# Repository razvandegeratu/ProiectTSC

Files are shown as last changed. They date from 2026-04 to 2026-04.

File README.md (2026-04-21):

Diagramă fără titlu drawio(1)

 Descrierea Funcționalității Hardware
Module și Interfețe

    Microcontroller: nRF52840 gestionează procesarea centrală.

    Display E-Paper: Comunică prin interfața SPI. S-a ales acest tip de ecran datorită consumului de energie zero în stare statică.

    Senzor IMU: Conectat prin I2C, utilizat pentru detectarea mișcării și orientării.

    Sistem de alimentare: Include un circuit de încărcare pentru bateria Li-Po și convertoare DC/DC pentru a asigura pragurile de tensiune de 3.3V necesare componentelor digitale.

    Interfață Utilizator: Trei butoane mecanice pentru navigare și un motor de vibrații pentru notificări haptice.

## Bill of Materials (BOM)

|Component|JLC Part #|Package|Description|Datasheet|
| :--- | :--- | :--- | :--- | :--- |
|C23, C27, C34, C42|[C21012218](https://www.lcsc.com/product-detail/C21012218.html)|-|Check availability|[datasheet](https://jlc-prod-smt.oss-eu-central-1.aliyuncs.com/smtDataManualFile/8603520985945550848-C21012218.pdf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)|
|R2_EP_DR, R9, R_PWR_EPD|[C3920633](https://www.lcsc.com/product-detail/C3920633.html)|0201|7.68k 0201 Thin Film Surface Mount Fixed Resistor +/-0.5% 0.031W CPF0201D7K68C1|[datasheet](https://wmsc.lcsc.com/wmsc/upload/file/pdf/v2/lcsc/2404081048_TE-Connectivity-CPF0201B511RE1_C3920633.pdf)|
|C1-EP-DR|[C9900156064](https://www.lcsc.com/product-detail/C9900156064.html)|201|Generic chip capacitor|[datasheet](https://ds.yuden.co.jp/TYCOMPAS/or/download?pn=MLAST063SCG681JFNA01&fileType=CA)|
|C2-EP-DR|[C9900156064](https://www.lcsc.com/product-detail/C9900156064.html)|201|Generic chip capacitor|[datasheet](https://ds.yuden.co.jp/TYCOMPAS/or/download?pn=MLAST063SCG681JFNA01&fileType=CA)|
|C11|[C9900156064](https://www.lcsc.com/product-detail/C9900156064.html)|201|Generic chip capacitor|[datasheet](https://ds.yuden.co.jp/TYCOMPAS/or/download?pn=MLAST063SCG681JFNA01&fileType=CA)|
|C24, C39|[C9900179830](https://www.lcsc.com/product-detail/C9900179830.html)|402|0402 (1005 Metric)|N/A|
|L2|[C12669](https://www.lcsc.com/product-detail/C12669.html)|402|Generic chip inductor|[datasheet](https://www.lcsc.com/datasheet/lcsc_datasheet_2304140030_Murata-Electronics-LQG15HS27NJ02D_C12669.pdf)|
|C1, C2, C17, C18|[C9900156064](https://www.lcsc.com/product-detail/C9900156064.html)|201|Generic chip capacitor|[datasheet](https://ds.yuden.co.jp/TYCOMPAS/or/download?pn=MLAST063SCG681JFNA01&fileType=CA)|
|L3|[C12669](https://www.lcsc.com/product-detail/C12669.html)|402|Generic chip inductor|[datasheet](https://www.lcsc.com/datasheet/lcsc_datasheet_2304140030_Murata-Electronics-LQG15HS27NJ02D_C12669.pdf)|
|C3, C4|[C9900156064](https://www.lcsc.com/product-detail/C9900156064.html)|201|Generic chip capacitor|[datasheet](https://ds.yuden.co.jp/TYCOMPAS/or/download?pn=MLAST063SCG681JFNA01&fileType=CA)|
|SJ1|N/A|Solder Jumper (Copper feature - leave open)|SMD solder JUMPER|N/A|
|C29, C30, C31, C32, C37, C38|[C3920633](https://www.lcsc.com/product-detail/C3920633.html)|0201|7.68k 0201 Thin Film Surface Mount Fixed Resistor +/-0.5% 0.031W CPF0201D7K68C1|[datasheet](https://wmsc.lcsc.com/wmsc/upload/file/pdf/v2/lcsc/2404081048_TE-Connectivity-CPF0201B511RE1_C3920633.pdf)|
|EPD_C1, EPD_C2, EPD_C6, EPD_C7, EPD_C8, EPD_C9, EPD_C10, EPD_C11, EPD_C12|[C9900156064](https://www.lcsc.com/product-detail/C9900156064.html)|201|Generic chip capacitor|[datasheet](https://ds.yuden.co.jp/TYCOMPAS/or/download?pn=MLAST063SCG681JFNA01&fileType=CA)|
|SW_DN, SW_ENT, SW_UP|[C569760](https://www.lcsc.com/product-detail/C569760.html)|SMD,3.9x2.9mm|-40℃~+85℃ 1.6N 1.6mm 15V 2.9mm 20mA 3.9mm 500,000 Cycles IP67 J-Lead Rectangular Button SPST Surface Mount,Vertical White With Bracket SMD,3.9x2.9mm Tactile Switches ROHS|[datasheet](https://wmsc.lcsc.com/wmsc/upload/file/pdf/v2/lcsc/2301111010_PANASONIC-EVPAKE31A_C569760.pdf)|
|Q1|[C2564](https://www.lcsc.com/product-detail/C2564.html)|TO-220AB|-55℃~+175℃ 1 P-Channel 180nC@10V 200W 20mΩ@10V 3.4nF 4V 55V 640pF 74A P-Channel TO-220AB MOSFETs ROHS|[datasheet](https://www.lcsc.com/datasheet/lcsc_datasheet_1809041724_Infineon-Technologies-IRF4905PBF_C2564.pdf)|
|C25, C33|[C9900179830](https://www.lcsc.com/product-detail/C9900179830.html)|402|0402 (1005 Metric)|N/A|
|ANT1|[C2917717](https://www.lcsc.com/product-detail/C2917717.html)|1206|-45℃~+125℃ 0.5dBi 1.3mm 1.6mm 100MHz 2.45GHz 2W 3.2mm 50Ω Patch Antenna 1206 Antennas ROHS|[datasheet](https://www.lcsc.com/datasheet/lcsc_datasheet_2404021210_Johanson-Dielectrics-2450AT18B100E_C2917717.pdf)|
|L1|[C12669](https://www.lcsc.com/product-detail/C12669.html)|402|Generic chip inductor|[datasheet](https://www.lcsc.com/datasheet/lcsc_datasheet_2304140030_Murata-Electronics-LQG15HS27NJ02D_C12669.pdf)|
|X2|[C32346](https://www.lcsc.com/product-detail/C32346.html)|SMD3215-2P|-40℃~+85℃ 12.5pF 32.768kHz 70kΩ Crystal Oscillator ±20ppm SMD3215-2P Crystals ROHS|[datasheet](https://www.lcsc.com/datasheet/lcsc_datasheet_2404180925_Seiko-Epson-Q13FC13500004_C32346.pdf)|
|X1|[C9009](https://www.lcsc.com/product-detail/C9009.html)|SMD3225-4P|-40℃~+85℃ 12pF 32MHz Crystal Oscillator ±10ppm ±20ppm SMD3225-4P Crystals ROHS|[datasheet](https://www.lcsc.com/datasheet/lcsc_datasheet_2403291504_YXC-Crystal-Oscillators-X322532MOB4SI_C9009.pdf)|
|R17, R18|[C3920633](https://www.lcsc.com/product-detail/C3920633.html)|0201|7.68k 0201 Thin Film Surface Mount Fixed Resistor +/-0.5% 0.031W CPF0201D7K68C1|[datasheet](https://wmsc.lcsc.com/wmsc/upload/file/pdf/v2/lcsc/2404081048_TE-Connectivity-CPF0201B511RE1_C3920633.pdf)|
|C43|[C9900156064](https://www.lcsc.com/product-detail/C9900156064.html)|201|Generic chip capacitor|[datasheet](https://ds.yuden.co.jp/TYCOMPAS/or/download?pn=MLAST063SCG681JFNA01&fileType=CA)|
|R1_EP_DR|[C3920633](https://www.lcsc.com/product-detail/C3920633.html)|0201|7.68k 0201 Thin Film Surface Mount Fixed Resistor +/-0.5% 0.031W CPF0201D7K68C1|[datasheet](https://wmsc.lcsc.com/wmsc/upload/file/pdf/v2/lcsc/2404081048_TE-Connectivity-CPF0201B511RE1_C3920633.pdf)|
|C6, C14, C20, C21|[C9900156064](https://www.lcsc.com/product-detail/C9900156064.html)|201|Generic chip capacitor|[datasheet](https://ds.yuden.co.jp/TYCOMPAS/or/download?pn=MLAST063SCG681JFNA01&fileType=CA)|
|EPD_C5|[C9900156064](https://www.lcsc.com/product-detail/C9900156064.html)|201|Generic chip capacitor|[datasheet](https://ds.yuden.co.jp/TYCOMPAS/or/download?pn=MLAST063SCG681JFNA01&fileType=CA)|
|D3|[C2969755](https://www.lcsc.com/product-detail/C2969755.html)|SOT-23-6L|Low Cap. ESD Protection Auto SOT-23-6 STMicroelectronics USBLC6-2SC6Y, Dual Uni-Directional TVS Diode Array, 6-Pin SOT-23|[datasheet](https://wmsc.lcsc.com/wmsc/upload/file/pdf/v2/lcsc/2211080730_STMicroelectronics-USBLC6-2SC6Y_C2969755.pdf)|
|C16|[C9900156064](https://www.lcsc.com/product-detail/C9900156064.html)|201|Generic chip capacitor|[datasheet](https://ds.yuden.co.jp/TYCOMPAS/or/download?pn=MLAST063SCG681JFNA01&fileType=CA)|
|J1|[C122434](https://www.lcsc.com/product-detail/C122434.html)|SMD,P=0.5mm,Surface Mount，Right Angle|FFC & FPC Connectors 0.5mm FPC RA SMT Dual Contact 24Ckt|[datasheet](https://www.molex.com/content/dam/molex/molex-dot-com/products/automated/en-us/salesdrawingpdf/503/503480/5034802400_sd.pdf)|
|R1_USB, R2_USB|[C3920633](https://www.lcsc.com/product-detail/C3920633.html)|0201|7.68k 0201 Thin Film Surface Mount Fixed Resistor +/-0.5% 0.031W CPF0201D7K68C1|[datasheet](https://wmsc.lcsc.com/wmsc/upload/file/pdf/v2/lcsc/2404081048_TE-Connectivity-CPF0201B511RE1_C3920633.pdf)|
|L5|[C1329646](https://www.lcsc.com/product-detail/C1329646.html)|SMD,4.8x4.8mm|1.6A 1.6A 4.7uH 41.4mΩ AEC-Q200 ±30% SMD,4.8x4.8mm Power Inductors ROHS|[datasheet](https://wmsc.lcsc.com/wmsc/upload/file/pdf/v2/lcsc/2304140030_BOURNS-SRR4828A-4R7Y_C1329646.pdf)|
|C9|[C9900156064](https://www.lcsc.com/product-detail/C9900156064.html)|201|Generic chip capacitor|[datasheet](https://ds.yuden.co.jp/TYCOMPAS/or/download?pn=MLAST063SCG681JFNA01&fileType=CA)|
|IC3|[C189517](https://www.lcsc.com/product-detail/C189517.html)|LGA-12(2x2)|Accelerometers Triaxial low-g 12bit Acceleration Sensor|[datasheet](https://www.lcsc.com/datasheet/C189517.pdf)|
|R5, R7, R8|[C3920633](https://www.lcsc.com/product-detail/C3920633.html)|0201|7.68k 0201 Thin Film Surface Mount Fixed Resistor +/-0.5% 0.031W CPF0201D7K68C1|[datasheet](https://wmsc.lcsc.com/wmsc/upload/file/pdf/v2/lcsc/2404081048_TE-Connectivity-CPF0201B511RE1_C3920633.pdf)|
|IC1|[C3682423](https://www.lcsc.com/product-detail/C3682423.html)|DSBGA-8(1.1x1.6)|Charger IC Lithium Ion/Polymer, Lithium Iron Phosphate 8-DSBGA (1.6x1.1)|[datasheet](https://www.ti.com/cn/lit/ds/symlink/bq25180.pdf?ts=1775594237116)|
|IC2|[C81079](https://www.lcsc.com/product-detail/C81079.html)|DSBGA-9|Haptic Driver for ERM/LRA with Built-In Library and Smart Loop Architecture|[datasheet](https://www.ti.com/cn/lit/gpn/drv2605)|
|C5, C7, C8, C12, C19|[C9900156064](https://www.lcsc.com/product-detail/C9900156064.html)|201|Generic chip capacitor|[datasheet](https://ds.yuden.co.jp/TYCOMPAS/or/download?pn=MLAST063SCG681JFNA01&fileType=CA)|
|C15|[C9900156064](https://www.lcsc.com/product-detail/C9900156064.html)|201|Generic chip capacitor|[datasheet](https://ds.yuden.co.jp/TYCOMPAS/or/download?pn=MLAST063SCG681JFNA01&fileType=CA)|
|R_TYPE_SEL|[C3920633](https://www.lcsc.com/product-detail/C3920633.html)|0201|7.68k 0201 Thin Film Surface Mount Fixed Resistor +/-0.5% 0.031W CPF0201D7K68C1|[datasheet](https://wmsc.lcsc.com/wmsc/upload/file/pdf/v2/lcsc/2404081048_TE-Connectivity-CPF0201B511RE1_C3920633.pdf)|
|L7|[C5832368](https://www.lcsc.com/product-detail/C5832368.html)|1008|13mΩ 470nH 6.5A 7.5A ±20% 1008 Power Inductors ROHS|[datasheet](https://wmsc.lcsc.com/wmsc/upload/file/pdf/v2/lcsc/2306021632_cjiang--Changjiang-Microelectronics-Tech-FTC252012SR47MBCA_C5832368.pdf)|
|TP (Test Pads)|N/A|N/A|Test pad|N/A|
|J4|[C709357](https://www.lcsc.com/product-detail/C709357.html)|SMD|-40℃~+85℃ 1 10,000 cycles 16P 30V 3A 7.81mm Female Surface Mount, Right Angle Type-C SMD USB Connectors ROHS|[datasheet](https://www.lcsc.com/datasheet/lcsc_datasheet_2404191039_Shenzhen-Kinghelm-Elec-KH-TYPE-C-16P_C709357.pdf)|
|U2|[C2682616](https://www.lcsc.com/product-detail/C2682616.html)|DFN-8-EP(2x2)|-40℃~+85℃ 1 2.5V~4.5V 3uA I2C Lithium Battery DFN-8-EP(2x2) Battery Management ROHS|[datasheet](https://www.lcsc.com/datasheet/lcsc_datasheet_2410121738_Analog-Devices-Inc--Maxim-Integrated-MAX17048G-T10_C2682616.pdf)|
|D2, D4, D5|[C82046](https://www.lcsc.com/product-detail/C82046.html)|SOD-123|ON SEMICONDUCTOR - MBR0530 - DIODE, SCHOTTKY, 0.5A, 30V, SOD-123|[datasheet](https://www.lcsc.com/datasheet/lcsc_datasheet_2304140030_onsemi-MBR0530T1G_C82046.pdf)|
|C10, C13, C22|[C9900156064](https://www.lcsc.com/product-detail/C9900156064.html)|201|Generic chip capacitor|[datasheet](https://ds.yuden.co.jp/TYCOMPAS/or/download?pn=MLAST063SCG681JFNA01&fileType=CA)|
|U1|[C3606653](https://www.lcsc.com/product-detail/C3606653.html)|QFN-48(6x6)|nRF52840|[datasheet](https://www.lcsc.com/datasheet/C3606653.pdf)|
|IC9|[C7065276](https://www.lcsc.com/product-detail/C7065276.html)|WLCSP-15B(2.3x1.4)|Buck-Boost Regulator Positive Output Step-Up/Step-Down I2C DC-DC Controller IC 15-WL-CSP (BSC) (1.4x2.3)|[datasheet](https://wmsc.lcsc.com/wmsc/upload/file/pdf/v2/lcsc/2312271436_Richtek-Tech-RT6160AWSC_C7065276.pdf)|
|Q3|[C469327](https://www.lcsc.com/product-detail/C469327.html)|SOT-323|MOSFET N-Ch 30V 1.5A TrenchFET SC70 Vishay Si1308EDL-T1-GE3 N-channel MOSFET Transistor, 1.5 A, 30 V, 3-Pin SC-70|[datasheet](https://www.lcsc.com/datasheet/lcsc_datasheet_1912202016_Vishay-Intertech-SI1308EDL-T1-GE3_C469327.pdf)|
|J2|[C90533](https://www.lcsc.com/product-detail/C90533.html)|P=1mm|CABLE ADAPTER 6 POS|[datasheet](https://wmsc.lcsc.com/wmsc/upload/file/pdf/v2/lcsc/1810141506_LX-FFC6P1-0mm7CM_C90533.pdf)|

5. Design Log și Decizii Tehnice

    PCB Stackup: Placa are o grosime de 1mm
    Plan de masă: S-au implementat planuri de masă pe ambele straturi (Top și Bottom) legate prin Via Stitching pentru a minimiza zgomotul electromagnetic, în special în zona circuitului radio.

    Antenă: Zona de sub antenă a fost decupată complet de planul de masă pe toate straturile pentru a asigura performanța optimă a semnalului BLE.

    Erori DRC acceptate: S-au ignorat erorile de tip "Dimension" la butoane și mufa USB-C deoarece acestea sunt necesare pentru alinierea mecanică cu carcasa, conform specificațiilor.

    Componente: Toate rezistențele și condensatoarele de decuplare (100nF) au fost plasate în capsulă 0201 cât mai aproape de pinii IC-urilor.

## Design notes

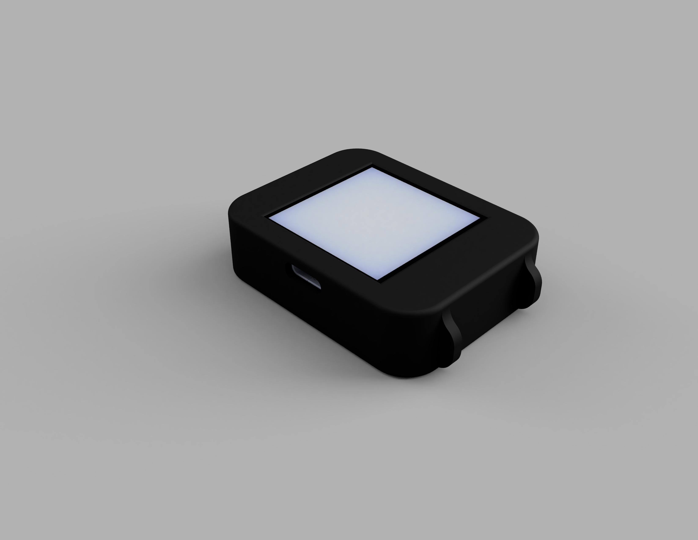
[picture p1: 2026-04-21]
Images/Final_2026-Apr-21_08-28-11PM-000_CustomizedView3443527159.jpg

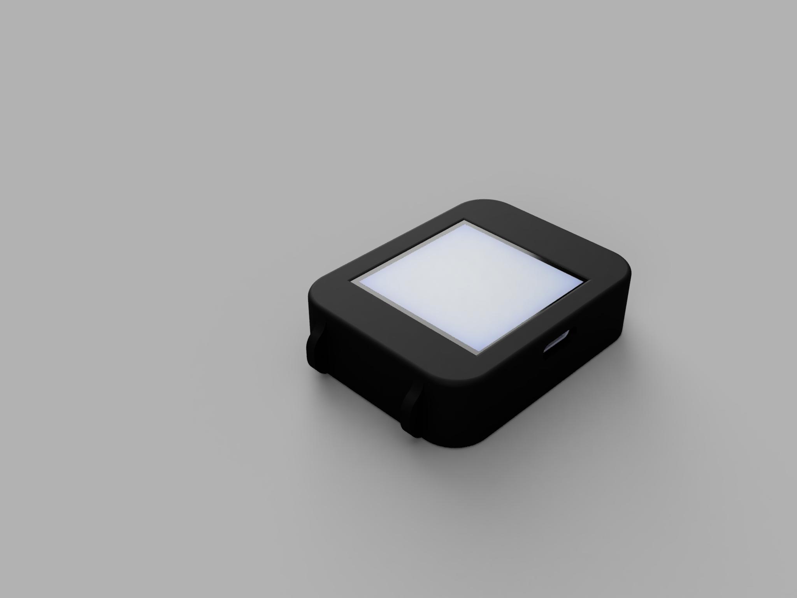
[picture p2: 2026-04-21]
Images/Final_2026-Apr-21_08-26-20PM-000_CustomizedView13817856768.jpg

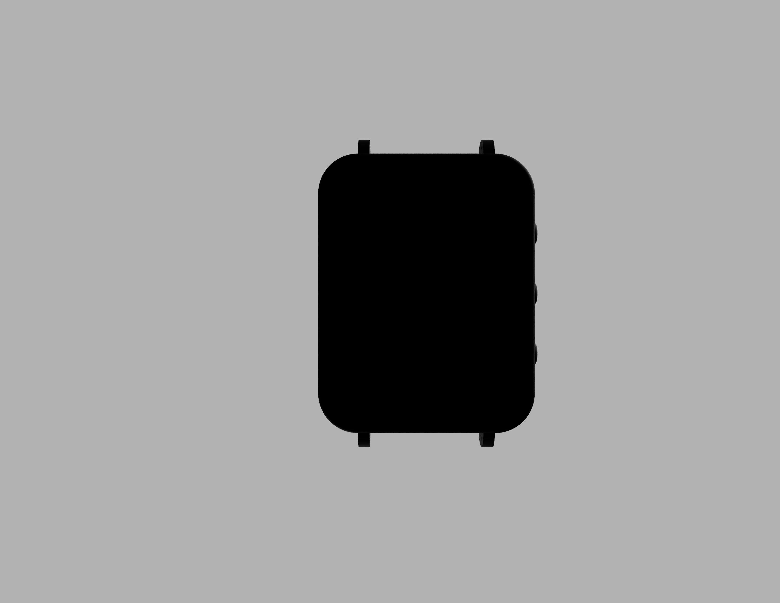
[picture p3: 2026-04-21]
Images/Final_2026-Apr-21_08-28-39PM-000_CustomizedView566863528.jpg

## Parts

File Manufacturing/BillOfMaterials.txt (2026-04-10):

Partlist exported from Proiect at 10/04/2026 17:19

Reference Designators                                                                         Quantity Description                                                                                                               Package                                       Value                                                   Manufacturer Manufacturer Part Number Vendor Vendor Part Number Top/Bottom 
                                                                                              1        PCB Board                                                                                                                 Board                                                                                                                                                                            
ANT1                                                                                          1        Antennas 2.45GHz ANTENNA                                                                                                  2450AT18B100E_ANTC3216X140N                   2450AT18B100E_2450AT18B100E                                                                                             Top        
C1, C2, C17, C18                                                                              4        Generic chip capacitor                                                                                                    NORDIC_NRF_3_RESC0201_L                       12pF                                                                                                                    Top        
C1-EP-DR, C24, C39                                                                            3        Generic chip capacitor                                                                                                    NORDIC_NRF_3_RESC0402_L                       10uF                                                                                                                    Top        
C2-EP-DR                                                                                      1        Generic chip capacitor                                                                                                    NORDIC_NRF_3_RESC0201_L                       4.7uF/25V                                                                                                               Top        
C3, C4                                                                                        2        Generic chip capacitor                                                                                                    NORDIC_NRF_3_RESC0201_L                       1pF                                                                                                                     Top        
C5, C7, C8, C12, C19                                                                          5        Generic chip capacitor                                                                                                    NORDIC_NRF_3_RESC0201_L                       100nF                                                                                                                   Top        
C6, C20, C21                                                                                  3        Generic chip capacitor                                                                                                    NORDIC_NRF_3_RESC0402_L                       4.7uF                                                                                                                   Top        
C9                                                                                            1        Generic chip capacitor                                                                                                    NORDIC_NRF_3_RESC0201_L                       820pF                                                                                                                   Top        
C10, C13, C22                                                                                 3        Generic chip capacitor                                                                                                    NORDIC_NRF_3_RESC0201_L                       N.C.                                                                                                                    Top        
C11                                                                                           1        Generic chip capacitor                                                                                                    NORDIC_NRF_3_RESC0201_L                       100pF                                                                                                                   Top        
C14                                                                                           1        0.22µF ceramic capacitors                                                                                                0402-TIGHT                                    4.7uF                                                                                                                   Top        
C15                                                                                           1        270pF/0.27nF ceramic capacitors                                                                                           0402-TIGHT                                    1.0uF                                                                                                                   Top        
C16                                                                                           1        Generic chip capacitor                                                                                                    NORDIC_NRF_3_RESC0201_L                       47nF                                                                                                                    Top        
C23, C42                                                                                      2        Check availability                                                                                                        -                                             0.1uF                                                                                                                   Top        
C25, C33                                                                                      2        Generic chip capacitor                                                                                                    NORDIC_NRF_3_RESC0402_L                       22uF                                                                                                                    Top        
C27, C34                                                                                      2        Check availability                                                                                                        GRM011R60J152KE01L_1_0201                     0.1uF                                                                                                                   Top        
C29, C30, C31, C37, C38                                                                       5        Check availability                                                                                                        -                                             1uF                                                                                                                     Top        
C32                                                                                           1        Check availability                                                                                                        GRM011R60J152KE01L_1_0201                     1uF                                                                                                                     Top        
C43                                                                                           1        Generic chip capacitor                                                                                                    NORDIC_NRF_3_RESC0402_L                       4.7uF\                                                                                                                  Top        
D2, D4, D5                                                                                    3        ON SEMICONDUCTOR - MBR0530 - DIODE, SCHOTTKY, 0.5A, 30V, SOD-123                                                          SOD3716X135N                                  ESP32_C6_LIBRARY_5_MBR0530                                                                                              Top        
D3                                                                                            1        Low Cap. ESD Protection Auto SOT-23-6 STMicroelectronics USBLC6-2SC6Y, Dual Uni-Directional TVS Diode Array, 6-Pin SOT-23 ESP32_C6_LIBRARY_3_SOT95P280X145-6N           USBLC6-2SC6Y                                                                                                            Top        
EPD_C1, EPD_C2, EPD_C6, EPD_C7, EPD_C8, EPD_C9, EPD_C10, EPD_C11, EPD_C12                     9        Generic chip capacitor                                                                                                    NORDIC_NRF_3_RESC0402_L                       1uF/50V                                                                                                                 Top        
EPD_C5                                                                                        1        Generic chip capacitor                                                                                                    NORDIC_NRF_3_RESC0201_L                       0.1uF/50V                                                                                                               Top        
IC1                                                                                           1        Charger IC Lithium Ion/Polymer, Lithium Iron Phosphate 8-DSBGA (1.6x1.1)                                                  BQ25180YBGR_BGA8C40P2X4_100X155X50            BQ25180YBGR_BQ25180YBGR                                                                                                 Top        
IC2                                                                                           1        Buck-Boost Regulator Positive Output Step-Up/Step-Down I2C DC-DC Controller IC 15-WL-CSP (BSC) (1.4x2.3)                  RT6160AWSC_BGA15C40P3X5_140X230X60            RT6160AWSC_RT6160AWSC                                                                                                   Top        
IC3                                                                                           1        Accelerometers Triaxial low-g 12bit Acceleration Sensor                                                                   BMA423_BMA423                                 BMA423_BMA423                                                                                                           Top        
IC4                                                                                           1        Haptic Driver for ERM/LRA with Built-In Library and Smart Loop Architecture                                               DRV2605YZFR_BGA9C50P3X3_144X144X62            DRV2605YZFR                                                                                                             Top        
J1                                                                                            1        CABLE ADAPTER 6 POS                                                                                                       TC2030-IDC_TC2030IDC                          TC2030-IDC_TC2030-IDC                                                                                                   Top        
J3                                                                                            1        FFC & FPC Connectors 0.5mm FPC RA SMT Dual Contact 24Ckt                                                                  503480-2400_5034802400                        503480-2400                                                                                                             Top        
J4                                                                                            1        Check availability                                                                                                        KH-TYPE-C-16P_KINGHELM_KH-TYPE-C-16P          KH-TYPE-C-16P                                                                                                           Top        
L1                                                                                            1        Generic chip inductor                                                                                                     NORDIC_NRF_2_RESC0402_L                       3.9nH                                                                                                                   Top        
L2                                                                                            1        Generic chip inductor                                                                                                     NORDIC_NRF_2_RESC0402_L                       10uH                                                                                                                    Top        
L3                                                                                            1        Generic chip inductor                                                                                                     NORDIC_NRF_2_RESC0402_L                       15nH                                                                                                                    Top        
L7                                                                                            1        SMD / SMT Inductors (Coils), L=0.47?H, L x W x T :                                                                        MLP2016SR47MT0S1_INDC2016X100N                MLP2016SR47MT0S1_FTC252012SR47MBCA                                                                                      Top        
Q1                                                                                            1        P-channel MOSFETs                                                                                                         ESP32_WROVER_SPARKFUN-DISCRETESEMI_SOT23-3    20V/4.2A/52mΩ/1.4W                                                                                                     Top        
Q3                                                                                            1        MOSFET N-Ch 30V 1.5A TrenchFET SC70 Vishay Si1308EDL-T1-GE3 N-channel MOSFET Transistor, 1.5 A, 30 V, 3-Pin SC-70         SOT65P210X110-3N                              ESP32_C6_LIBRARY_6_SI1308EDL-T1-GE3                                                                                     Top        
R_PWR_EPD, R2_EP_DR, R5, R7, R8, R9                                                           6        7.68k 0201 Thin Film Surface Mount Fixed Resistor +/-0.5% 0.031W CPF0201D7K68C1                                           CPF0201D7K68C1_0201                           10K                                                                                                                     Top        
R_TYPE_SEL                                                                                    1        7.68k 0201 Thin Film Surface Mount Fixed Resistor +/-0.5% 0.031W CPF0201D7K68C1                                           CPF0201D7K68C1_0201                           2.2                                                                                                                     Top        
R1                                                                                            1        7.68k 0201 Thin Film Surface Mount Fixed Resistor +/-0.5% 0.031W CPF0201D7K68C1                                           CPF0201D7K68C1_0201                           CPF0201D7K68C1_CPF0201D7K68C1                                                                                           Top        
R1_EP_DR                                                                                      1        7.68k 0201 Thin Film Surface Mount Fixed Resistor +/-0.5% 0.031W CPF0201D7K68C1                                           CPF0201D7K68C1_0201                           0.47                                                                                                                    Top        
R1_USB                                                                                        1        7.68k 0201 Thin Film Surface Mount Fixed Resistor +/-0.5% 0.031W CPF0201D7K68C1                                           CPF0201D7K68C1_0201                           5.1K ohm                                                                                                                Top        
R2, R4                                                                                        2        7.68k 0201 Thin Film Surface Mount Fixed Resistor +/-0.5% 0.031W CPF0201D7K68C1                                           CPF0201D7K68C1_0201                           0                                                                                                                       Top        
R2_USB                                                                                        1        7.68k 0201 Thin Film Surface Mount Fixed Resistor +/-0.5% 0.031W CPF0201D7K68C1                                           CPF0201D7K68C1_0201                           5.1K                                                                                                                    Top        
R17                                                                                           1        7.68k 0201 Thin Film Surface Mount Fixed Resistor +/-0.5% 0.031W CPF0201D7K68C1                                           R0201                                         3.3K                                                                                                                    Top        
R18                                                                                           1        7.68k 0201 Thin Film Surface Mount Fixed Resistor +/-0.5% 0.031W CPF0201D7K68C1                                           R0201                                         3.3k                                                                                                                    Top        
SJ1                                                                                           1        SMD solder JUMPER                                                                                                         JUMPER_SJ                                                                                                                                                             Top        
SW_DN, SW_ENT, SW_UP                                                                          3                                                                                                                                  2025-10-22_07-23-44_LIBRARY_SW_EVP-AKE31A_PAN 2025-10-22_07-23-44_LIBRARY_EVP-AKE31ASW_EVP-AKE31A_PAN                                                                 Top        
TP_BAT_GND, TP_ON, TP_OP, TP_SCL, TP_SDA, TP_SWDCLK, TP_SWDIO, TP_SWO, TP_VBAT, TP3, TP4, TP6 12       Test pad                                                                                                                  HECTOR_WATCH_1_TP20R                          HECTOR_WATCH_1_TPTP20R                                                                                                  Top        
U$1                                                                                           1        nRF52840                                                                                                                  NORDIC_NRF_4_AQFN50P700X700X85_HS-74N         NORDIC_NRF_4_NRF52840_QF                                                                                                Top        
U$2                                                                                           1        Generic chip inductor                                                                                                     NORDIC_NRF_2_RESC0402_L                                                                                                                                               Top        
U3                                                                                            1        Check availability                                                                                                        ESP32_C6_LIBRARY_SON50P200X200X80-9N          MAX17048G+T10                                                                                                           Top        
X1                                                                                            1                                                                                                                                  NORDIC_NRF_BT-XTAL_2016_N                     32MHz                                                                                                                   Top        
X2                                                                                            1                                                                                                                                  NORDIC_NRF_1_XTAL_3215_N                      32.768kHz                                                                                                               Top

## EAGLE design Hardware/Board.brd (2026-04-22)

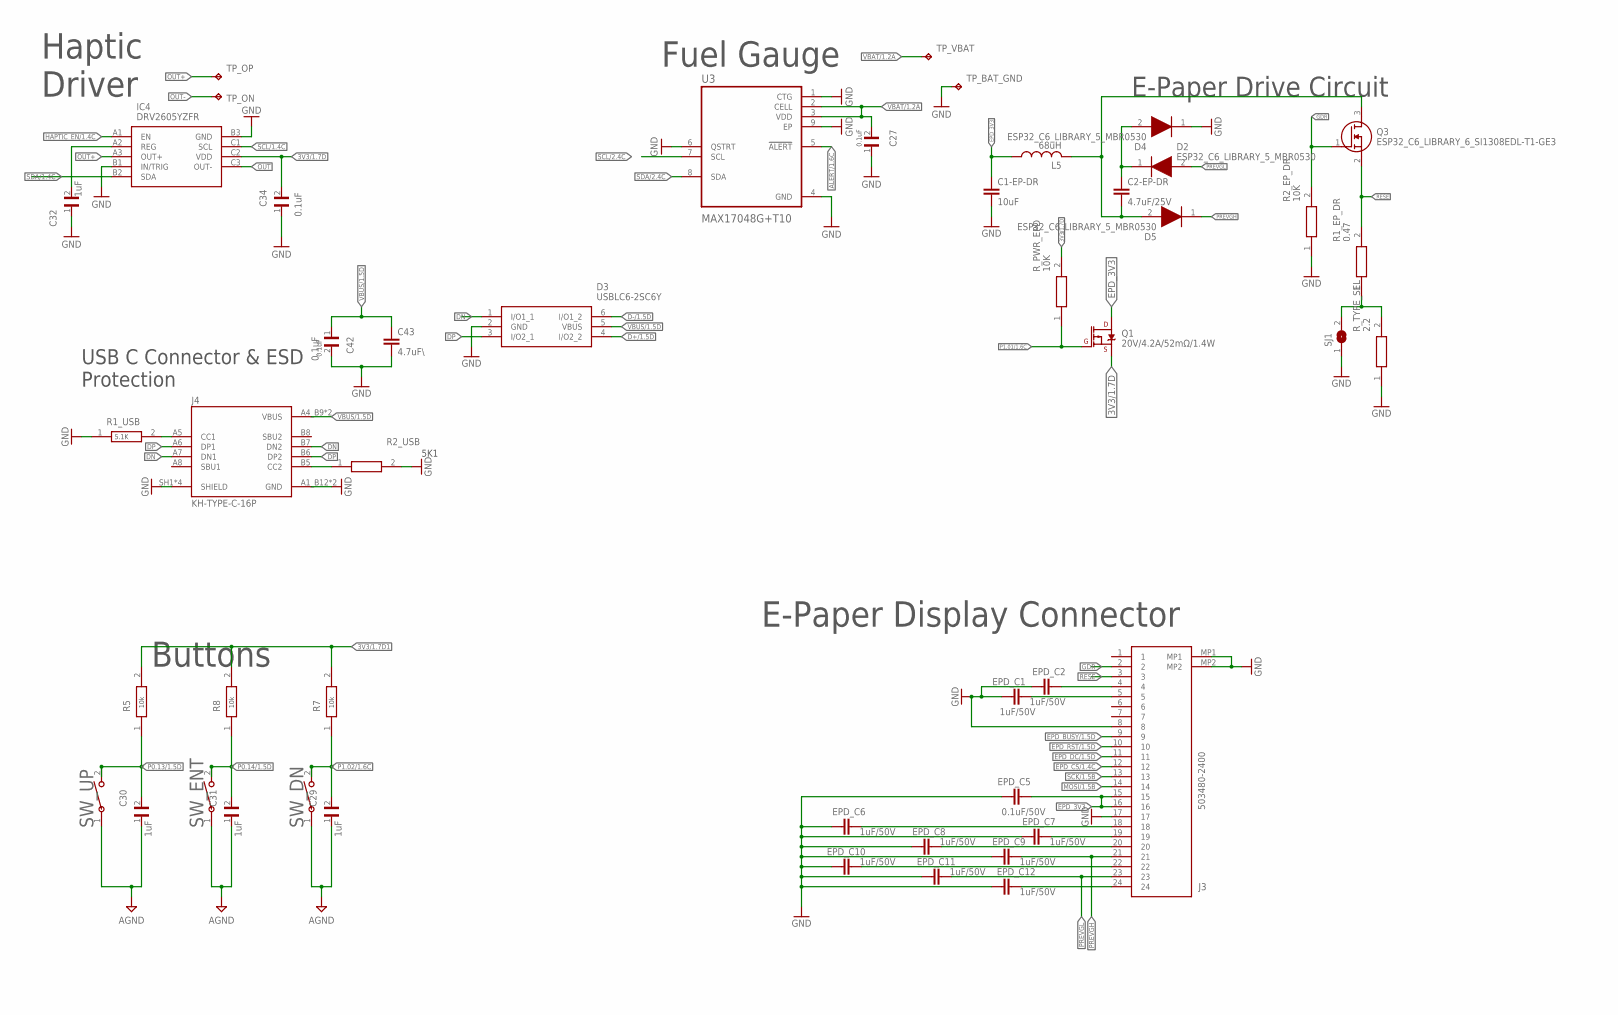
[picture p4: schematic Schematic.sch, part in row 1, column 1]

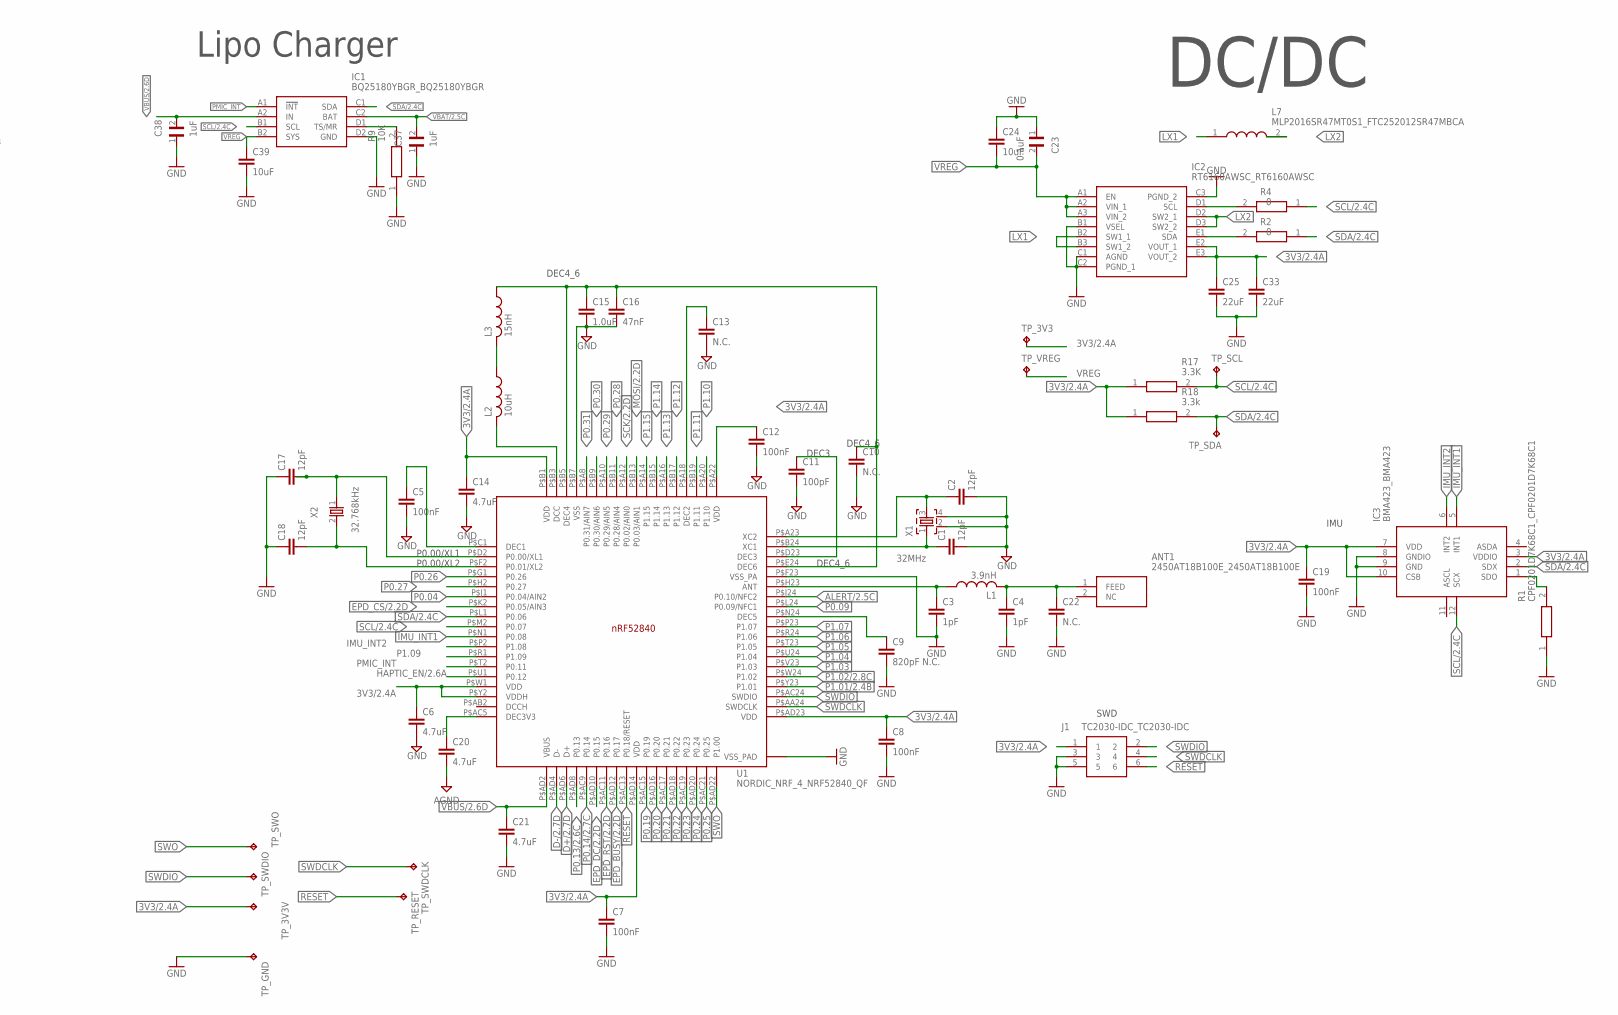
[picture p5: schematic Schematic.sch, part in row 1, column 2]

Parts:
ANT1: 2450AT18B100E_2450AT18B100E; 2450AT18B100E_ANTC3216X140N
C1, C2, C17, C18: 12pF; NORDIC_NRF_3_RESC0201_L
C1-EP-DR, C24, C39: 10uF; NORDIC_NRF_3_RESC0402_L
C2-EP-DR: 4.7uF/25V; NORDIC_NRF_3_RESC0201_L
C3, C4: 1pF; NORDIC_NRF_3_RESC0201_L
C5, C7, C8, C12, C19: 100nF; NORDIC_NRF_3_RESC0201_L
C6, C20, C21: 4.7uF; NORDIC_NRF_3_RESC0402_L
C9: 820pF N.C.; NORDIC_NRF_3_RESC0201_L
C10, C13, C22: N.C.; NORDIC_NRF_3_RESC0201_L
C11: 100pF; NORDIC_NRF_3_RESC0201_L
C14: 4.7uF; 0402-TIGHT
C15: 1.0uF; 0402-TIGHT
C16: 47nF; NORDIC_NRF_3_RESC0201_L
C23, C42: 0.1uF; GRM011R60J152KE01L_2_CAPC0201X13N
C25, C33: 22uF; NORDIC_NRF_3_RESC0402_L
C27, C34: 0.1uF; GRM011R60J152KE01L_1_0201
C29, C30, C31, C37, C38: 1uF; GRM011R60J152KE01L_2_CAPC0201X13N
C32: 1uF; GRM011R60J152KE01L_1_0201
C43: 4.7uF\; NORDIC_NRF_3_RESC0402_L
D2, D4, D5: ESP32_C6_LIBRARY_5_MBR0530; ESP32_C6_LIBRARY_5_SOD3716X135N
D3: USBLC6-2SC6Y; ESP32_C6_LIBRARY_3_SOT95P280X145-6N
EPD_C1, EPD_C2, EPD_C6, EPD_C7, EPD_C8, EPD_C9, EPD_C10, EPD_C11, EPD_C12: 1uF/50V; NORDIC_NRF_3_RESC0402_L
EPD_C5: 0.1uF/50V; NORDIC_NRF_3_RESC0201_L
IC1: BQ25180YBGR_BQ25180YBGR; BQ25180YBGR_BGA8C40P2X4_100X155X50
IC2: RT6160AWSC_RT6160AWSC; RT6160AWSC_BGA15C40P3X5_140X230X60
IC3: BMA423_BMA423
IC4: DRV2605YZFR; DRV2605YZFR_BGA9C50P3X3_144X144X62
J1: TC2030-IDC_TC2030-IDC; TC2030-IDC_TC2030IDC
J3: 503480-2400; 503480-2400_5034802400
J4: KH-TYPE-C-16P; KH-TYPE-C-16P_KINGHELM_KH-TYPE-C-16P
L1: 3.9nH; NORDIC_NRF_2_RESC0402_L
L2: 10uH; NORDIC_NRF_2_RESC0402_L
L3: 15nH; NORDIC_NRF_2_RESC0402_L
L5: 68uH; NORDIC_NRF_2_RESC0402_L
L7: MLP2016SR47MT0S1_FTC252012SR47MBCA; MLP2016SR47MT0S1_INDC2016X100N
Q1: 20V/4.2A/52mΩ/1.4W; ESP32_C6_LIBRARY_4_ESP32_C6_LIBRARY_4_ESP32_C6_LIBRARY_4_ES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
Q3: ESP32_C6_LIBRARY_6_SI1308EDL-T1-GE3; ESP32_C6_LIBRARY_6_SOT65P210X110-3N
R1: CPF0201D7K68C1_CPF0201D7K68C1; CPF0201D7K68C1_0201
R1_EP_DR: 0.47; CPF0201D7K68C1_0201
R1_USB: 5.1K ohm; CPF0201D7K68C1_0201
R2, R4: 0; CPF0201D7K68C1_0201
R2_EP_DR, R5, R7, R8, R9: 10K; CPF0201D7K68C1_0201
R2_USB: 5.1K; CPF0201D7K68C1_0201
R17: 3.3K; ERA-1AEB3401C_0201
R18: 3.3k; ERA-1AEB3401C_0201
R_PWR_EPD: 10K; CPF0201D7K68C1_0201
R_TYPE_SEL: 2.2; CPF0201D7K68C1_0201
SJ1: ESP32_C6_LIBRARY_7_JUMPER_SJ
SW_DN: 2025-10-22_07-23-44_LIBRARY_EVP-AKE31ASW_EVP-AKE3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; 2025-10-22_07-23-44_LIBRARY_SW_EVP-AKE31A_PAN
SW_ENT: 2025-10-22_07-23-44_LIBRARY_EVP-AKE31ASW_EVP-AKE3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; 2025-10-22_07-23-44_LIBRARY_SW_EVP-AKE31A_PAN
SW_UP: 2025-10-22_07-23-44_LIBRARY_EVP-AKE31ASW_EVP-AKE3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; 2025-10-22_07-23-44_LIBRARY_SW_EVP-AKE31A_PAN
TP_3V3, TP_3V3V: HECTOR_WATCH_1_TPTP20R; HECTOR_WATCH_1_TP20R
TP_BAT_GND: HECTOR_WATCH_1_TPTP20R; HECTOR_WATCH_1_TP20R
TP_GND: HECTOR_WATCH_1_TPTP20R; HECTOR_WATCH_1_TP20R
TP_ON: HECTOR_WATCH_1_TPTP20R; HECTOR_WATCH_1_TP20R
TP_OP: HECTOR_WATCH_1_TPTP20R; HECTOR_WATCH_1_TP20R
TP_RESET: HECTOR_WATCH_1_TPTP20R; HECTOR_WATCH_1_TP20R
TP_SCL: HECTOR_WATCH_1_TPTP20R; HECTOR_WATCH_1_TP20R
TP_SDA: HECTOR_WATCH_1_TPTP20R; HECTOR_WATCH_1_TP20R
TP_SWDCLK: HECTOR_WATCH_1_TPTP20R; HECTOR_WATCH_1_TP20R
TP_SWDIO: HECTOR_WATCH_1_TPTP20R; HECTOR_WATCH_1_TP20R
TP_SWO: HECTOR_WATCH_1_TPTP20R; HECTOR_WATCH_1_TP20R
TP_VBAT: HECTOR_WATCH_1_TPTP20R; HECTOR_WATCH_1_TP20R
TP_VREG: HECTOR_WATCH_1_TPTP20R; HECTOR_WATCH_1_TP20R
U1: NORDIC_NRF_4_NRF52840_QF; NORDIC_NRF_4_AQFN50P700X700X85_HS-74N
U3: MAX17048G+T10; ESP32_C6_LIBRARY_SON50P200X200X80-9N
X1: 32MHz; NORDIC_NRF_BT-XTAL_2016_N
X2: 32.768kHz; NORDIC_NRF_1_XTAL_3215_N

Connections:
3V3/1.7D: C34.2, IC4.C2 (VDD), Q1.2 (S), R_PWR_EPD.2
3V3/1.7D1: R5.2, R7.2, R8.2
3V3/2.4A: C6.1, C7.1, C8.1, C12.1, C14.1, C19.1, C25.1, C33.1, IC2.E2 (VOUT_1), IC2.E3 (VOUT_2), IC3.3 (VDDIO), IC3.7 (VDD), IC3.10 (CSB), J1.1, R17.1, R18.1, TP_3V3.TP, TP_3V3V.TP, U1.P$A22 (VDD), U1.P$AD14 (VDD), U1.P$AD23 (VDD), U1.P$B1 (VDD), U1.P$W1 (VDD), U1.P$Y2 (VDDH)
ALERT/1.6C: U3.5 (!ALERT)
ALERT/2.5C: U1.P$J24 (P0.10/NFC2)
D+/1.5D: D3.4 (I/O2_2)
D+/2.7D: U1.P$AD6 (D+)
D-/1.5D: D3.6 (I/O1_2)
D-/2.7D: U1.P$AD4 (D-)
DN: D3.1 (I/O1_1), J4.A7 (DN1), J4.B7 (DN2)
DP: D3.3 (I/O2_1), J4.A6 (DP1), J4.B6 (DP2)
EPD_3V3: C1-EP-DR.1, EPD_C5.2, J3.15, J3.16, L5.1, Q1.3 (D)
EPD_BUSY/1.5D: J3.9
EPD_BUSY/2.2D: U1.P$AD12 (P0.17)
EPD_CS/1.4C: J3.12
EPD_CS/2.2D: U1.P$K2 (P0.05/AIN3)
EPD_DC/1.5D: J3.11
EPD_DC/2.2D: U1.P$AD10 (P0.15)
EPD_RST/1.5D: J3.10
EPD_RST/2.2D: U1.P$AC11 (P0.16)
GDR: J3.2, Q3.1 (G), R2_EP_DR.2
GND: C1.2, C1-EP-DR.2, C2.2, C3.2, C4.2, C5.2, C6.2, C7.2, C8.2, C9.2, C10.2, C11.2, C12.2, C13.2, C14.2, C15.2, C16.2, C17.1, C18.1, C19.2, C20.2, C21.2, C22.2, C23.1, C24.1, C25.2, C27.1, C29.1, C30.1, C31.1, C32.1, C33.2, C34.1, C37.1, C38.1, C39.2, C42.2, C43.2, D3.2 (GND), D4.1 (K), EPD_C1.1, EPD_C2.1, EPD_C5.1, EPD_C6.1, EPD_C7.1, EPD_C8.1, EPD_C9.1, EPD_C10.1, EPD_C11.1, EPD_C12.1, IC1.D2 (GND), IC2.B1 (VSEL), IC2.C1 (AGND), IC2.C2 (PGND_1), IC2.C3 (PGND_2), IC3.8 (GNDIO), IC3.9 (GND), IC4.B1 (IN/TRIG), IC4.B3 (GND), J1.3, J1.5, J3.8, J3.17, J3.MP1, J3.MP2, J4.A1_B12 (GND), J4.A12_B1 (GND), J4.SH1 (SHIELD), J4.SH2 (SHIELD), J4.SH3 (SHIELD), J4.SH4 (SHIELD), R1.1, R1_USB.1, R2_EP_DR.1, R2_USB.2, R9.1, R_TYPE_SEL.1, SJ1.1, SW_DN.1, SW_ENT.1, SW_UP.1, TP_BAT_GND.TP, TP_GND.TP, U1.P$74 (VSS_PAD), U1.P$75 (VSS_PAD), U1.P$76 (VSS_PAD), U1.P$77 (VSS_PAD), U1.P$78 (VSS_PAD), U1.P$79 (VSS_PAD), U1.P$80 (VSS_PAD), U1.P$81 (VSS_PAD), U1.P$82 (VSS_PAD), U1.P$83 (VSS_PAD), U1.P$84 (VSS_PAD), U1.P$85 (VSS_PAD), U1.P$86 (VSS_PAD), U1.P$87 (VSS_PAD), U1.P$88 (VSS_PAD), U1.P$89 (VSS_PAD), U1.P$90 (VSS_PAD), U1.P$B7 (VSS), U1.P$F23 (VSS_PA), U3.1 (CTG), U3.4 (GND), U3.6 (QSTRT), U3.9 (EP), X1.2, X1.4
HAPTIC_EN/1.4C: IC4.A1 (EN)
HAPTIC_EN/2.6A: U1.P$U1 (P0.12)
IMU_INT1: IC3.5 (INT1), U1.P$N1 (P0.08)
IMU_INT2: IC3.6 (INT2), U1.P$P2 (P1.08)
LX1: IC2.B2 (SW1_1), IC2.B3 (SW1_2), L7.1
LX2: IC2.D2 (SW2_1), IC2.D3 (SW2_2), L7.2
MOSI/1.5B: J3.14
MOSI/2.2D: U1.P$B13 (P0.03/AIN1)
unnamed: C20.1, U1.P$AC5 (DEC3V3)
unnamed: C18.2, U1.P$F2 (P0.01/XL2), X2.2
unnamed: L2.2, U1.P$B3 (DCC)
unnamed: L2.1, L3.2
unnamed: C1.1, U1.P$B24 (XC1), X1.1
unnamed: C13.1, U1.P$A18 (DEC2)
unnamed: C11.1, U1.P$D23 (DEC3)
unnamed: C10.1, C15.1, C16.1, L3.1, U1.P$B5 (DEC4), U1.P$E24 (DEC6)
unnamed: C17.2, U1.P$D2 (P0.00/XL1), X2.1
unnamed: C5.1, U1.P$C1 (DEC1)
unnamed: C2.1, U1.P$A23 (XC2), X1.3
unnamed: C3.1, L1.1, U1.P$H23 (ANT)
unnamed: ANT1.1 (FEED), C4.1, C22.1, L1.2
unnamed: IC1.D1 (TS/MR), R9.2
unnamed: C9.1, U1.P$N24 (DEC5)
unnamed: IC2.D1 (SCL), R4.2
unnamed: IC3.1 (SDO), R1.2
unnamed: C32.2, IC4.A2 (REG)
unnamed: J4.A5 (CC1), R1_USB.2
unnamed: IC2.E1 (SDA), R2.2
unnamed: C2-EP-DR.1, D2.1 (K), D4.2 (A)
unnamed: C2-EP-DR.2, D5.2 (A), L5.2, Q3.3 (D)
unnamed: R1_EP_DR.1, R_TYPE_SEL.2, SJ1.2
unnamed: J4.B5 (CC2), R2_USB.1
unnamed: EPD_C2.2, J3.4
unnamed: EPD_C1.2, J3.5
unnamed: EPD_C6.2, J3.18
unnamed: EPD_C7.2, J3.19
unnamed: EPD_C8.2, J3.20
unnamed: EPD_C10.2, J3.22
unnamed: EPD_C12.2, J3.24
OUT: IC4.C3 (OUT-)
OUT+: IC4.A3 (OUT+), TP_OP.TP
OUT-: TP_ON.TP
P0.04: U1.P$J1 (P0.04/AIN2)
P0.09: U1.P$L24 (P0.09/NFC1)
P0.13/1.5D: C30.2, R5.1, SW_UP.2
P0.13/2.6C: U1.P$AD8 (P0.13)
P0.14/1.5D: C31.2, R8.1, SW_ENT.2
P0.14/2.7C: U1.P$AC9 (P0.14)
P0.19: U1.P$AC15 (P0.19)
P0.20: U1.P$AD16 (P0.20)
P0.21: U1.P$AC17 (P0.21)
P0.22: U1.P$AD18 (P0.22)
P0.23: U1.P$AC19 (P0.23)
P0.24: U1.P$AD20 (P0.24)
P0.25: U1.P$AC21 (P0.25)
P0.26: U1.P$G1 (P0.26)
P0.27: U1.P$H2 (P0.27)
P0.28: U1.P$B11 (P0.28/AIN4)
P0.29: U1.P$A10 (P0.29/AIN5)
P0.30: U1.P$B9 (P0.30/AIN6)
P0.31: U1.P$A8 (P0.31/AIN7)
P1.01/1.6C: Q1.1 (G), R_PWR_EPD.1
P1.01/2.4B: U1.P$Y23 (P1.01)
P1.02/1.6C: C29.2, R7.1, SW_DN.2
P1.02/2.8C: U1.P$W24 (P1.02)
P1.03: U1.P$V23 (P1.03)
P1.04: U1.P$U24 (P1.04)
P1.05: U1.P$T23 (P1.05)
P1.06: U1.P$R24 (P1.06)
P1.07: U1.P$P23 (P1.07)
P1.09: U1.P$R1 (P1.09)
P1.10: U1.P$A20 (P1.10)
P1.11: U1.P$B19 (P1.11)
P1.12: U1.P$B17 (P1.12)
P1.13: U1.P$A16 (P1.13)
P1.14: U1.P$B15 (P1.14)
P1.15: U1.P$A14 (P1.15)
PMIC_INT: IC1.A1 (!INT), U1.P$T2 (P0.11)
PREVGH: D5.1 (K), EPD_C9.2, J3.21
PREVGL: D2.2 (A), EPD_C11.2, J3.23
RESE: J3.3, Q3.2 (S), R1_EP_DR.2
RESET: J1.6, TP_RESET.TP, U1.P$AC13 (P0.18/RESET)
SCK/1.5B: J3.13
SCK/2.2D: U1.P$A12 (P0.02/AIN0)
SCL/1.4C: IC4.C1 (SCL)
SCL/2.4C: IC1.B1 (SCL), IC3.12 (SCX), R4.1, R17.2, TP_SCL.TP, U1.P$M2 (P0.07), U3.7 (SCL)
SDA/1.4C: IC4.B2 (SDA)
SDA/2.4C: IC1.C1 (SDA), IC3.2 (SDX), R2.1, R18.2, TP_SDA.TP, U1.P$L1 (P0.06), U3.8 (SDA)
SWDCLK: J1.4, TP_SWDCLK.TP, U1.P$AA24 (SWDCLK)
SWDIO: J1.2, TP_SWDIO.TP, U1.P$AC24 (SWDIO)
SWO: TP_SWO.TP, U1.P$AD22 (P1.00)
VBAT/1.2A: C27.2, TP_VBAT.TP, U3.2 (CELL), U3.3 (VDD)
VBAT/2.5C: C37.2, IC1.C2 (BAT)
VBUS/1.5D: C42.1, C43.1, D3.5 (VBUS), J4.A4_B9 (VBUS), J4.A9_B4 (VBUS)
VBUS/2.6D: C21.1, C38.2, IC1.A2 (IN), U1.P$AD2 (VBUS)
VREG: C23.2, C24.2, C39.1, IC1.B2 (SYS), IC2.A1 (EN), IC2.A2 (VIN_1), IC2.A3 (VIN_2), TP_VREG.TP

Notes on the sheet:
SWD
Lipo Charger
DC/DC
Fuel Gauge
0.1uF
Haptic Driver
5.1K
5K1
USB C Connector & ESD Protection
E-Paper Display Connector
E-Paper Drive Circuit
Buttons
10k
IMU
DEC4_6
DEC3
P0.00/XL1
P0.00/XL2

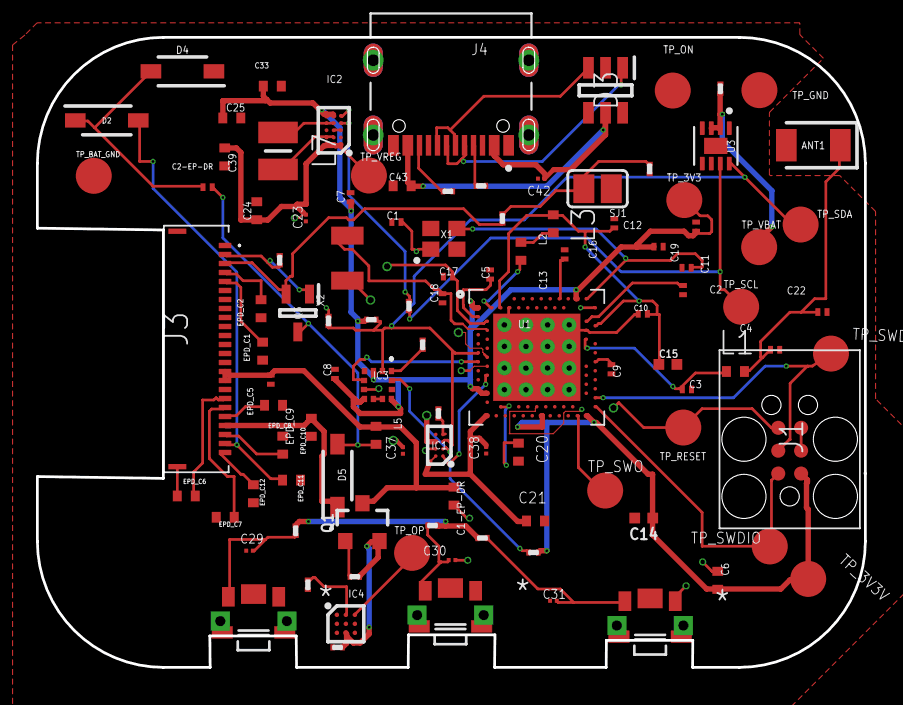
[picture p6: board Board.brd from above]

Board: 4 copper layers, 46.0 x 35.0 mm, 105 parts (0 on the bottom side), 63 nets.

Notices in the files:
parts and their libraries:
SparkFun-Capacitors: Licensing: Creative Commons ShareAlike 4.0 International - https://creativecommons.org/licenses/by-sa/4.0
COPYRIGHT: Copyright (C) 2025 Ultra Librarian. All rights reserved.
